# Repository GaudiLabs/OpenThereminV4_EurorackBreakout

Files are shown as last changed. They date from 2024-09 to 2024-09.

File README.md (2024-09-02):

# OpenThereminV4_EurorackBreakout
Break-Out-Modules for the OpenTheremin V45
Copyright (C) by GaudiLabs published under a public license.

OpenThereminV4 board design files:
https://github.com/GaudiLabs/OpenThereminV4

The Break-Out board uses the mocoLUFA firmware
Copyright (C) by morecat_lab
https://github.com/kuwatay/mocolufa

OpenTheremin V4 Eurorack Kits are available here:
https://gaudishop.ch/

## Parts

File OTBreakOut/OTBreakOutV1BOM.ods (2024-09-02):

 | BOM OTBreakOut V1
Id | Quantity | Designator | Designation | Package |  | Price | Supplier and ref | Stock | 25 | ordered
1 | 1 | U1 | ATmega16U2-M | QFN-32-1EP_5x5mm_P0.5mm_EP3.1x3.1mm | 556-ATMEGA16U2-MU |  | mouser | 5 | 25 | 25
22 | 1 | U2 | AP2205-50Y-13 | SOT-89-3 | 621-AP2205-50Y-13 |  | mouser | 23 | 25 | 100
18 | 1 | U3 | AD8531ARTZ-R7 | SOT-23-5 | 584-AD8531ARTZ-R7 |  | mouser | 10 | 25 | 30
8 | 4 | C2,C4,C5,C1 | 22pF | C_0603_1608Metric |  |  |  | 2000 | 100
9 | 1 | C3 | 1uF | C_0603_1608Metric |  |  | stock | 5000 | 25
19 | 2 | C6, C8 | 10nF | C_0603_1608Metric |  |  |  | 22nF 1200 | 50
17 | 1 | C7 | 47uF | C_0805_2012Metric |  |  |  | 300 | 25
11 | 2 | C9,C10 | 100nF | C_0603_1608Metric |  |  |  | 5000 | 50
20 | 2 | D1, D2 | D_Schottky | D_SOD-123 | 841-PMEG3005EGWX |  | mouser | 120 | 50
21 | 1 | Y1 | Crystal_GND24 | Crystal_SMD_3225-4Pin_3.2x2.5mm | 581-CX3225GB16DHEQCC |  | mouser | 95 | 25
2 | 2 | R1,R2 | 22R | R_0603_1608Metric |  |  |  | 1000 | 50
14 | 3 | R10,R11,R9 | 10k | R_0603_1608Metric |  |  |  | 2000 | 75
15 | 2 | R12,R13 | 5.1k | R_0603_1608Metric | order |  |  |  | 50 | 5000
25 | 1 | R3 | 1M | R_0603_1608Metric |  |  |  | 5000 | 25
23 | 2 | R6,R8 | 220R | R_0603_1608Metric |  |  |  | 5000 | 50
16 | 1 | R7 | 2.2k | R_0603_1608Metric |  |  |  | 5000 | 25
24 | 1 | J1 | AudioJack3 | Jack_3.5mm_QingPu_WQP-PJ366ST_Vertical |  |  |  | 16 | 25
3 | 4 | J2,J3,J4,J5 | AudioJack2_Ground_SwitchT | Jack_3.5mm_QingPu_WQP-PJ398SM_Vertical |  |  |  | 87 | 100
10 | 1 | J6 | DIN-5_180degree | Deltron_691-0500 |  |  |  | 100 | 25
 | 1 |  |  | Deltron Ring Nut |  |  |  | 100 | 25
28 | 1 | J7 | Conn_02x05_Odd_Even | PinHeader_2x05_P2.54mm_Vertical | 710-61201021621 |  |  | 0 | 25 | 50
12 | 1 | J8 | USB_C_Receptacle | UJ40_CVG_SMT_TR | 179-UJ40CVGSMTTR | 3.79 | mouser | 16 | 25 | 15
4 | 1 | J10 | Conn_02x05_Odd_Even | PinHeader_2x05_P1.27mm_Vertical_SMD | 649-20215210010C1LF |  |  | 6 | 25 | 30
5 | 1 | RV1 | R_Potentiometer | Potentiometer_Alpha_RD901F-40-00D_Single_Vertical |  |  |  | 0 | 25
26 | 1 | JP1 | Jumper_2_Bridged | SolderJumper-2_P1.3mm_Open_RoundedPad1.0x1.5mm
6 | 2 | FID1,FID2 | Fiducial | Fiducial_1mm_Mask2mm
 | 1 | PCB | Modular Beakout PCB |  |  |  |  | 25 | 25

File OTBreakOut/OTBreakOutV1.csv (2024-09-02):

Id | Designator | Package | Quantity | Designation | Supplier and ref
1 | U1 | QFN-32-1EP_5x5mm_P0.5mm_EP3.1x3.1mm | 1 | ATmega16U2-M
2 | R1,R2 | R_0603_1608Metric | 2 | 22R
3 | J2,J4,J5,J3 | Jack_3.5mm_QingPu_WQP-PJ398SM_Vertical | 4 | AudioJack2_Ground_SwitchT
4 | J10 | PinHeader_2x05_P1.27mm_Vertical_SMD | 1 | Conn_02x05_Odd_Even
5 | RV1 | Potentiometer_Alpha_RD901F-40-00D_Single_Vertical | 1 | R_Potentiometer
6 | FID1,FID2 | Fiducial_1mm_Mask2mm | 2 | Fiducial
7 | C8 | C_0603_1608Metric | 1 | 10uF
8 | C2,C4,C5,C1 | C_0603_1608Metric | 4 | 22pF
9 | C3 | C_0603_1608Metric | 1 | 1uF
10 | J6 | Deltron_691-0500 | 1 | DIN-5_180degree
11 | C9,C10 | C_0603_1608Metric | 2 | 100nF
12 | J8 | UJ40_CVG_SMT_TR | 1 | USB_C_Receptacle
13 | D2 | D_SOD-123 | 1 | D_Small_Filled
14 | R10,R11,R9 | R_0603_1608Metric | 3 | 10k
15 | R12,R13 | R_0603_1608Metric | 2 | 5.1k
16 | R7 | R_0603_1608Metric | 1 | 2.2k
17 | C7 | C_0805_2012Metric | 1 | 47uF
18 | U3 | SOT-23-5 | 1 | LMH6609MF
19 | C6 | C_0603_1608Metric | 1 | 10nF
20 | D1 | D_SOD-123 | 1 | D_Schottky
21 | Y1 | Crystal_SMD_3225-4Pin_3.2x2.5mm | 1 | Crystal_GND24
22 | U2 | SOT-23 | 1 | MCP1792x-5002xCB XC62KN5002MR-G
23 | R6,R8 | R_0603_1608Metric | 2 | 220R
24 | J1 | Jack_3.5mm_QingPu_WQP-PJ366ST_Vertical | 1 | AudioJack3
25 | R3 | R_0603_1608Metric | 1 | 1M
26 | JP1 | SolderJumper-2_P1.3mm_Open_RoundedPad1.0x1.5mm | 1 | Jumper_2_Bridged
27 | J9 | Tag-Connect_TC2030-IDC-NL_2x03_P1.27mm_Vertical | 1 | Conn_02x03_Odd_Even
28 | J7 | PinHeader_2x05_P2.54mm_Vertical | 1 | Conn_02x05_Odd_Even
29 | X1 | Smile | 1 | dummy

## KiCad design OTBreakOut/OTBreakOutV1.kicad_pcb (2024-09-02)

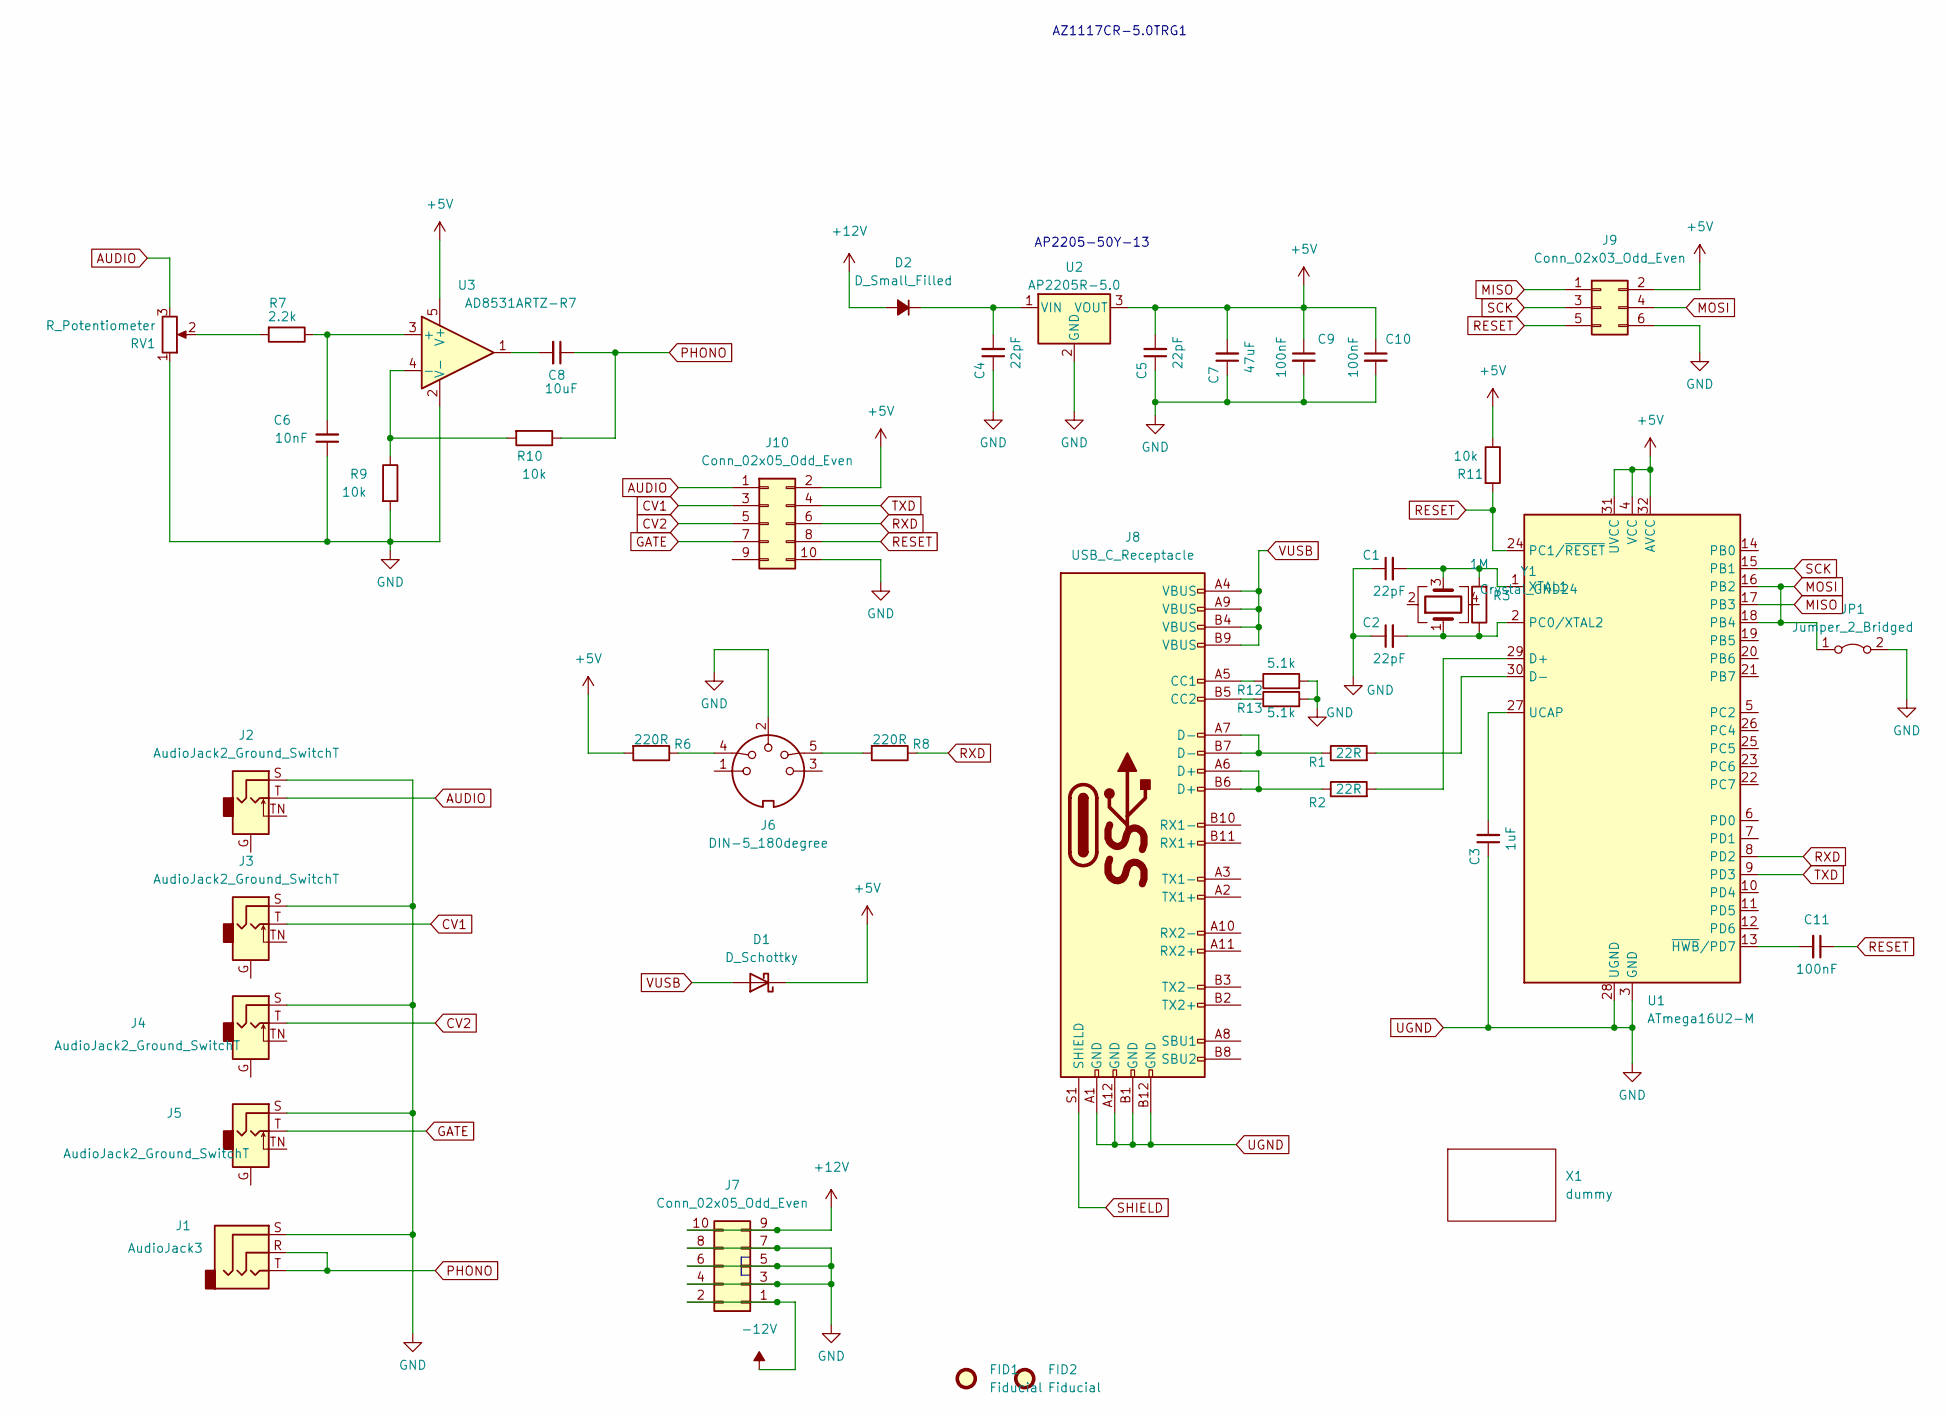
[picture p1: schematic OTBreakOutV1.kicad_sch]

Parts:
C1, C2, C4, C5: 22pF; C_0603_1608Metric
C3: 1uF; C_0603_1608Metric
C6: 10nF; C_0603_1608Metric
C7: 47uF; C_0805_2012Metric
C8: 10uF; C_0603_1608Metric
C9, C10, C11: 100nF; C_0603_1608Metric
D1: D_Schottky; D_SOD-123
D2: D_Small_Filled; D_SOD-123
FID1, FID2: Fiducial; Fiducial_1mm_Mask2mm
J1: AudioJack3; Jack_3.5mm_QingPu_WQP-PJ366ST_Vertical
J2, J3, J4, J5: AudioJack2_Ground_SwitchT; Jack_3.5mm_Stereo_WQP-PJ366ST_Vertical
J6: DIN-5_180degree; Deltron_691-0500
J7: Conn_02x05_Odd_Even; ModularConnector_10pin
J8: USB_C_Receptacle; UJ40_CVG_SMT_TR
J9: Conn_02x03_Odd_Even; Tag-Connect_TC2030-IDC-NL_2x03_P1.27mm_Vertical
J10: Conn_02x05_Odd_Even; OTBreakOut_2x05_P1.27mm_Vertical_SMD
JP1: Jumper_2_Bridged; SolderJumper-2_P1.3mm_Open_RoundedPad1.0x1.5mm
R1, R2: 22R; R_0603_1608Metric
R3: 1M; R_0603_1608Metric
R6, R8: 220R; R_0603_1608Metric
R7: 2.2k; R_0603_1608Metric
R9, R10, R11: 10k; R_0603_1608Metric
R12, R13: 5.1k; R_0603_1608Metric
RV1: R_Potentiometer; Alps_RK09K_Vertical
U1: ATmega16U2-M; QFN-32-1EP_5x5mm_P0.5mm_EP3.1x3.1mm
U2: AP2205R-5.0; SOT-89-3
U3: AD8531ARTZ-R7; SOT-23-5
X1: dummy; Smile
Y1: Crystal_GND24; Crystal_SMD_3225-4Pin_3.2x2.5mm

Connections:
+5V: C5.2, C7.2, C9.1, C10.1, D1.1 (K), J9.2, J10.2, R6.2, R11.1, U1.4 (VCC), U1.31 (UVCC), U1.32 (AVCC), U2.3 (VOUT), U3.5 (V+)
+12V: D2.2 (A), J7.9, J7.10
-12V: J7.1, J7.2
AUDIO: J2.T, J10.1, RV1.3
CV1: J3.T, J10.3
CV2: J4.T, J10.5
GATE: J5.T, J10.7
MISO: J9.1, U1.17 (PB3)
MOSI: J9.4, JP1.1 (A), U1.16 (PB2), U1.18 (PB4)
unnamed: C1.2, R3.2, U1.1 (XTAL1), Y1.3
unnamed: C2.2, R3.1, U1.2 (PC0/XTAL2), Y1.1
unnamed: C3.2, U1.27 (UCAP)
unnamed: C4.2, D2.1 (K), U2.1 (VIN)
unnamed: C6.2, R7.1, U3.3 (+)
unnamed: C8.2, U3.1
unnamed: J6.4, R6.1
unnamed: J6.5, R8.2
unnamed: J8.A5 (CC1), R12.1
unnamed: J8.A6 (D+), J8.B6 (D+), R2.1
unnamed: J8.A7 (D-), J8.B7 (D-), R1.1
unnamed: J8.B5 (CC2), R13.1
unnamed: R1.2, U1.30 (D-)
unnamed: R2.2, U1.29 (D+)
unnamed: R7.2, RV1.2
unnamed: R9.1, R10.2, U3.4 (-)
unnamed: C11.2, U1.13 (~HWB/PD7)
PHONO: C8.1, J1.R, J1.T, R10.1
RESET: C11.1, J9.5, J10.8, R11.2, U1.24 (PC1/~RESET)
RXD: J10.6, R8.1, U1.8 (PD2)
SCK: J9.3, U1.15 (PB1)
TXD: J10.4, U1.9 (PD3)
UGND: C1.1, C2.1, C3.1, C4.1, C5.1, C6.1, C7.1, C9.2, C10.2, J1.S, J2.S, J3.S, J4.S, J5.S, J6.2, J7.3, J7.4, J7.5, J7.6, J7.7, J7.8, J8.A1 (GND), J8.A12 (GND), J8.B1 (GND), J8.B12 (GND), J9.6, J10.10, JP1.2 (B), R9.2, R12.2, R13.2, RV1.1, U1.3 (GND), U1.28 (UGND), U1.33 (GND), U2.2 (GND), U3.2 (V-)
VUSB: D1.2 (A), J8.A4 (VBUS), J8.A9 (VBUS), J8.B4 (VBUS), J8.B9 (VBUS)

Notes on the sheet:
AZ1117CR-5.0TRG1
AP2205-50Y-13

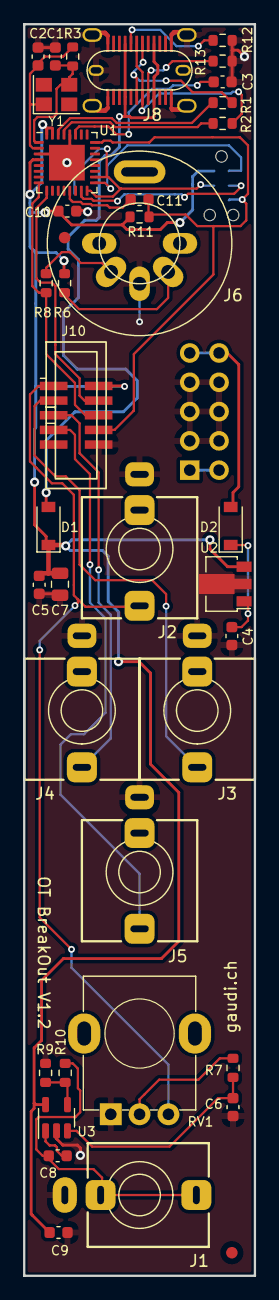
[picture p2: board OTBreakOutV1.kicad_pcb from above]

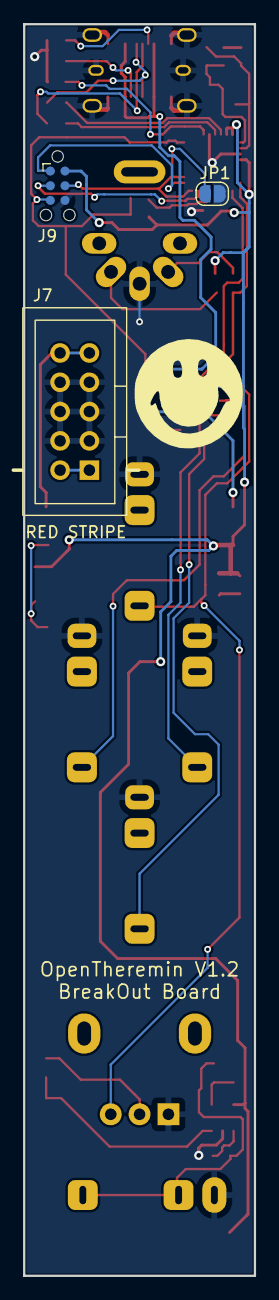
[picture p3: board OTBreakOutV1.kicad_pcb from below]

Board: 2 copper layers, 20.0 x 108.5 mm, 43 parts (4 on the bottom side), 33 nets.
